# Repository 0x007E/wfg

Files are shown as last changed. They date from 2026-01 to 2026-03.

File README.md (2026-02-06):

  

# `WFG` - Waveform Generator (Signalgenerator)

The `WFG` is a board with an [LM324](#additional-information) or any other 4-channel operational amplifier. The board itself is driven with a voltage of `5V`. It generates a triange and a pwm signal. Both signals can be adjustet through the onboard trimmer. When the board is connected to a voltage source the `green` led signals the readiness.

Optional the generated signals can be readin with an external interrupt and a internal running timmer on a microcontroller and status data can be sent to a terminal over UART. A demo how this can be done is attached and can be tested with an [ATmega16A](#additional-information).

> This design is derived form Analog Devices. Details can be found [here](https://www.analog.com/en/resources/design-notes/pulsewidth-modulator-operates-at-various-levels-of-frequency-and-power.html)

| Experience | Level |
|:---|:-----:|
| Soldering | ?% |
| Software | ?% |

# Downloads

| Type | File | Description |
|:---:|:---:|:---|
| Simulation | [asc](https://github.com/0x007E/wfg/raw/refs/heads/main/WFG.asc) | LTSpice Simulation | 
| Lochmaster | [lm4](https://github.com/0x007E/wfg/raw/refs/heads/main/WFG.LM4) | Stripe grid circuit board | 
| Schematic | [pdf](https://github.com/0x007E/wfg/releases/latest/download/schematic.pdf) / [cadlab](https://cadlab.io/project/29870/main/files) | Schematic files |
| Board | [pdf](https://github.com/0x007E/wfg/releases/latest/download/pcb.pdf) / [cadlab](https://cadlab.io/project/29870/main/files) | Board file |
| Drill | [pdf](https://github.com/0x007E/wfg/releases/latest/download/drill.pdf) | Drill file |
| PCB | [zip](https://github.com/0x007E/wfg/releases/latest/download/kicad.zip) / [tar](https://github.com/0x007E/wfg/releases/latest/download/kicad.tar.gz) |  	KiCAD/Gerber/BoM/Drill files |
| Firmware | [zip](https://github.com/0x007E/wfg/releases/latest/download/firmware.zip) / [tar](https://github.com/0x007E/wfg/releases/latest/download/firmware.tar.gz) | Demo Firmware for ATmega16 |

# Hardware

The pcb is created with `KiCAD`. All files are built with `github actions` so that they are ready for a production environment.

## PCB

The circuit board is populated on one side. The best way for soldering the `SMD` components is within a vapor phase soldering system and for the `THT` components with a standard system.

### Top Layer

Top Layer

### Bottom Layer

Bottom Layer

# Configuration

Within the different trimmers the waveforms can be adjustet in height, frequency and duty cycle.

# Software

The demo firmware (`ATmega16A`) of the `WFG` can be used to measure the frequency and duty cycle of the generated PWM signal and transmit the data over uart to a terminal.

## Dataflow diagram

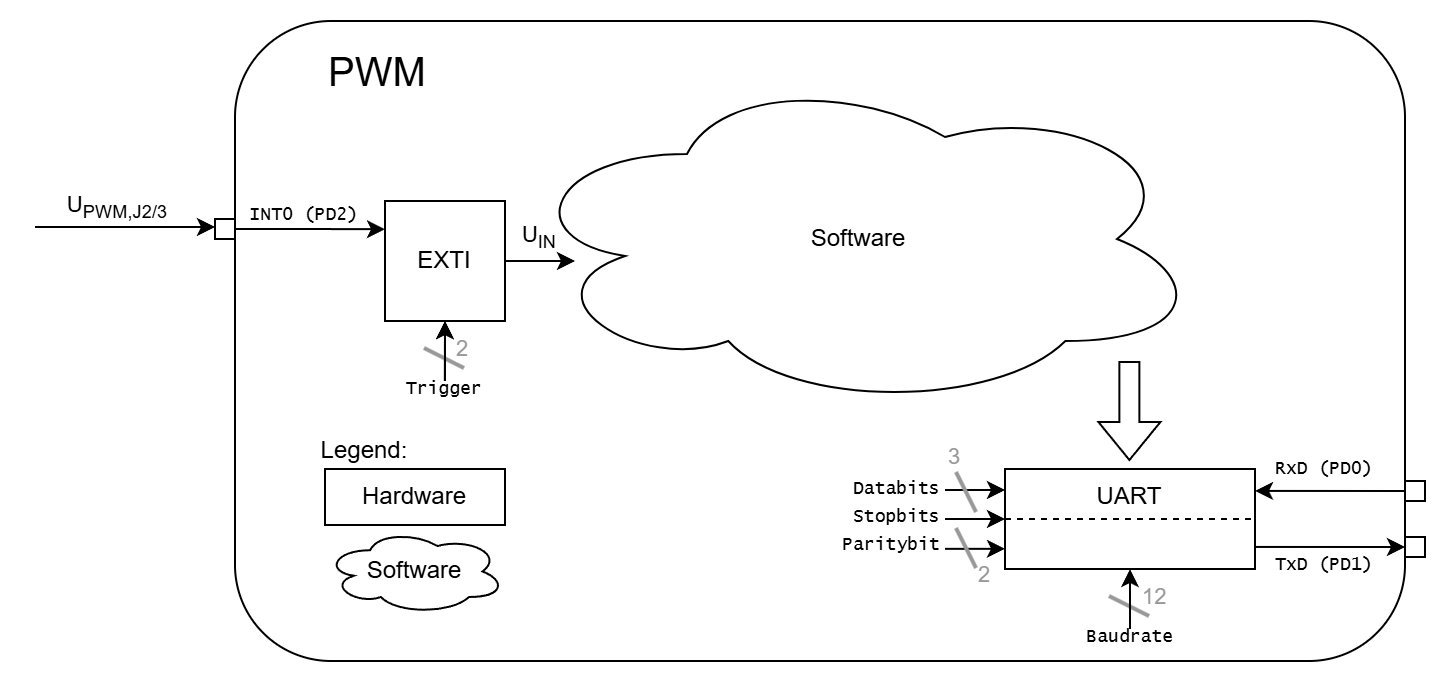
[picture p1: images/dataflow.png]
Dataflow


# Additional Information

| Type | Link | Description |
|:---:|:---:|:---|
| LM324 | [pdf](https://www.ti.com/lit/ds/symlink/lm324.pdf) | Quad operational amplifier |
| ATmega16A | [pdf](https://ww1.microchip.com/downloads/en/devicedoc/atmel-8154-8-bit-avr-atmega16a_datasheet.pdf) | Microchip ATmega16A Datasheet |

---

R. GAECHTER

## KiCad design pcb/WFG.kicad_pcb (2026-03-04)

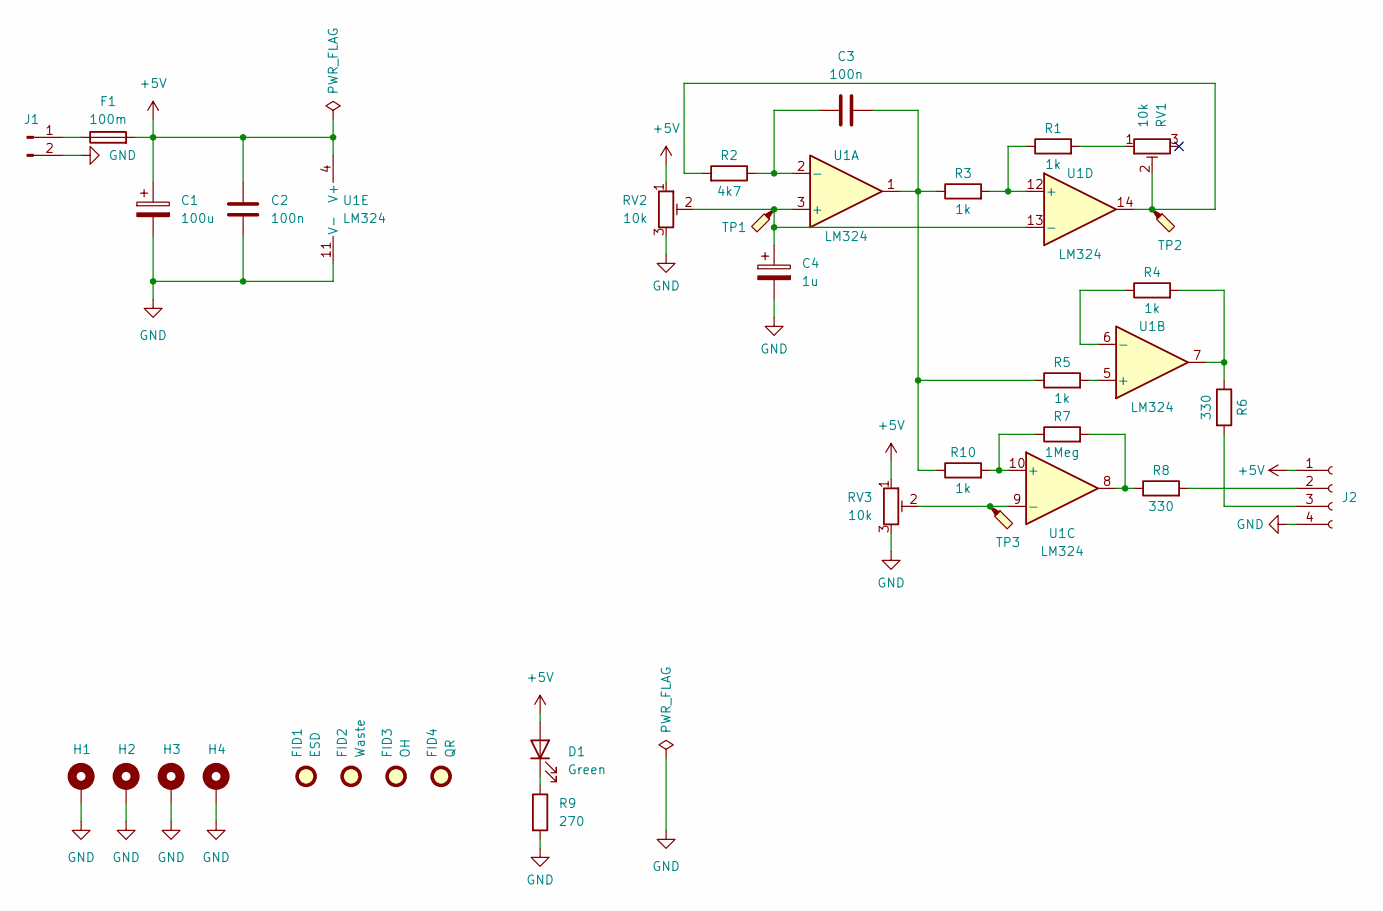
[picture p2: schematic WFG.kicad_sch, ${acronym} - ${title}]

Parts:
C1: 100u; CP_Elec_6.3x4.9
C2, C3: 100n; C_1206_3216Metric
C4: 1u; CP_EIA-3528-21_Kemet-B
D1: Green; LED_1206_3216Metric
F1: 100m; Fuse_1206_3216Metric
FID1: ESD; ESD-Logo_6.6x6mm_SilkScreen
FID2: Waste; WEEE-Logo_4.2x6mm_SilkScreen
FID3: OH; OSHW-Logo_5.7x6mm_SilkScreen
FID4: QR; QR_0x007e
H1, H2, H3, H4: MountingHole_Pad; MountingHole_3.2mm_M3_DIN965_Pad
J1: Conn_01x02_Pin; PinHeader_1x02_P2.54mm_Vertical
J2: Conn_01x04_Socket; PinSocket_1x04_P2.54mm_Vertical
R1, R3, R4, R5, R10: 1k; R_1206_3216Metric
R2: 4k7; R_1206_3216Metric
R6, R8: 330; R_1206_3216Metric
R7: 1Meg; R_1206_3216Metric
R9: 270; R_1206_3216Metric
RV1, RV2, RV3: 10k; Potentiometer_Bourns_3296W_Vertical
TP1, TP2, TP3: TestPoint_Probe; TestPoint_Pad_D1.5mm
U1: LM324; SOIC-14_3.9x8.7mm_P1.27mm

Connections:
+5V: C1.1, C2.1, D1.2 (A), F1.2, J2.1, RV2.1, RV3.1, U1.4 (V+)
GND: C1.2, C2.2, C4.2, H1.1, H2.1, H3.1, H4.1, J1.2, J2.4, R9.2, RV2.3, RV3.3, U1.11 (V-)
unnamed: C3.2, R3.1, R5.1, R10.1, U1.1
unnamed: D1.1 (K), R9.1
unnamed: F1.1, J1.1
unnamed: J2.2, R8.2
unnamed: J2.3, R6.2
unnamed: R1.2, RV1.1
unnamed: R2.2, RV1.2, TP2.1, U1.14
unnamed: R4.2, R6.1, U1.7
unnamed: R7.2, R8.1, U1.8
unnamed: C4.1, RV2.2, TP1.1, U1.3 (+), U1.13 (-)
unnamed: C3.1, R2.1, U1.2 (-)
unnamed: R5.2, U1.5 (+)
unnamed: R4.1, U1.6 (-)
unnamed: R7.1, R10.2, U1.10 (+)
unnamed: RV3.2, TP3.1, U1.9 (-)
unnamed: R1.1, R3.2, U1.12 (+)

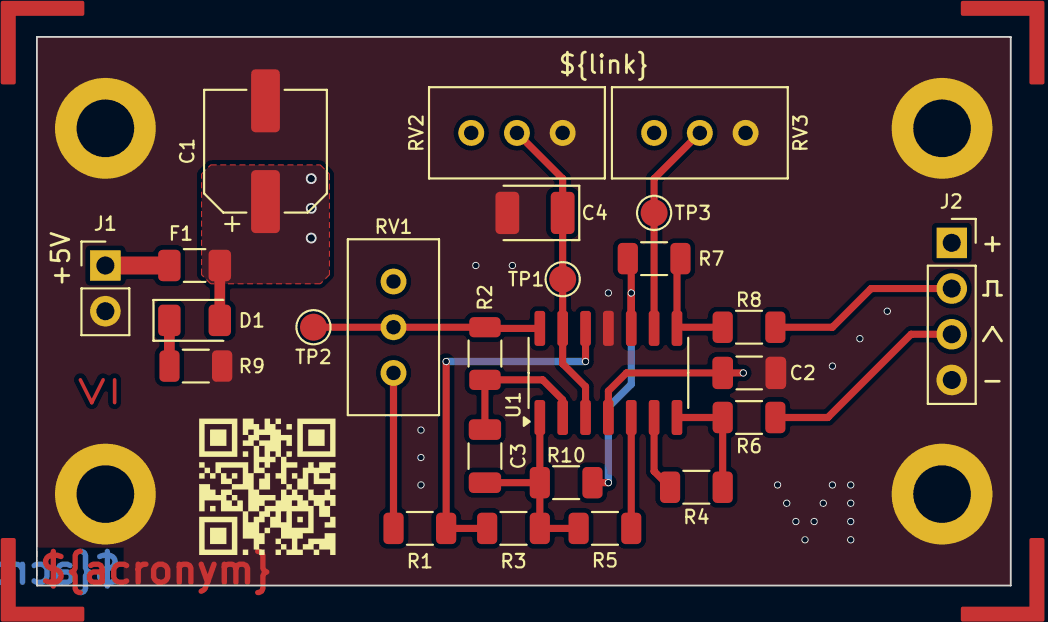
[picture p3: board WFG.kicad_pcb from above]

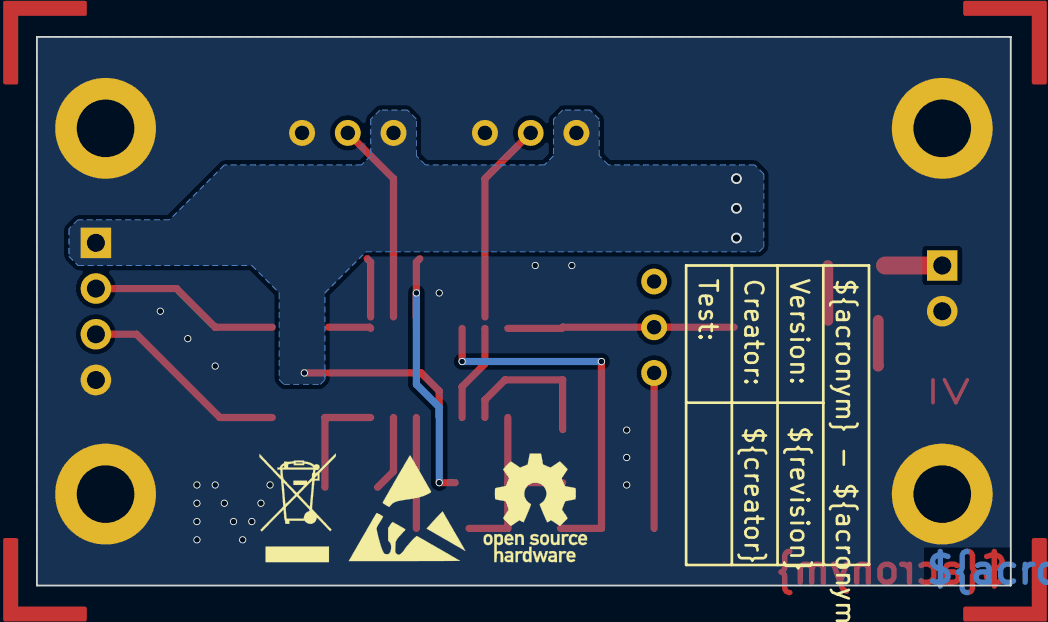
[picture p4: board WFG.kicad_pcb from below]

Board: 2 copper layers, 54.1 x 30.5 mm, 33 parts (3 on the bottom side), 18 nets.

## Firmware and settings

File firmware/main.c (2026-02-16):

#define F_CPU 12000000UL

#include <avr/io.h>
#include <avr/interrupt.h>
#include <util/delay.h>

#include "uart/uart.h"

volatile unsigned int tick_counter;
volatile unsigned int last_rise_time;
volatile unsigned int period_ticks;

volatile unsigned char dutycycle;
volatile unsigned int frequency;

ISR(INT0_vect)
{
    sei();
    unsigned int now = tick_counter;

    if (PIND & (1<<PIND2))
    {
        last_rise_time = now;
    }
    else
    {
        unsigned int high_ticks = now - last_rise_time;
        static unsigned int previous_rise_time = 0;
        
        period_ticks = last_rise_time - previous_rise_time;
        previous_rise_time = last_rise_time;
        
        if (period_ticks != 0)
        {
            dutycycle = (unsigned char)((high_ticks * 100UL) / period_ticks);
            frequency = (unsigned int)(100000UL / period_ticks);
        }
    }
}

ISR(TIMER0_COMP_vect)
{
    tick_counter++;
}

static void external_init(void)
{
    DDRD &= ~(1<<PIND2);	// Input
    PORTD |= (1<<PIND2);	// Pull-up
    
    MCUCR = (1<<ISC00);		// Any logical change
    GICR = (1<<INT0);		// Enable interrupt
}

static void timer_init(void)
{
    OCR0 = 119;
    TCCR0 = (1<<WGM01) | (1<<CS00);
    TIMSK = (1<<OCIE0);
}

int main(void)
{
    external_init();
    timer_init();
    sei();
    
    uart_init();
    
    while (1) 
    {
        printf("Duty Cycle: %3u, Frequency: %5u   \r", dutycycle, frequency);
        
        _delay_ms(200);
    }
}

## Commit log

2026-01-23 Add pcb layout
    [WFG.kicad_pcb, WFG.kicad_sch]
2026-01-30 Fix LM324 wiring
    [WFG.kicad_pcb, WFG.kicad_sch]
2026-01-30 Fix wiring fault
2026-02-03 Fix naming of part identifiers
    [WFG.kicad_pcb, WFG.kicad_sch]
2026-02-03 Adapt naming of pcb download section
2026-02-03 Add missing vendor
    [WFG.kicad_pcb, WFG.kicad_sch]
2026-02-06 Fix 0V connection
2026-03-04 Fix fabrication layer layout
    [WFG.kicad_pcb]

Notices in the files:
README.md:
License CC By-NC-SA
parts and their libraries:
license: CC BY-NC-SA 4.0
